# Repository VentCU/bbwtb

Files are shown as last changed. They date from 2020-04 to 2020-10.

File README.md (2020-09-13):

# VentCU
> A radically accessible, affordable, and producible ventilator. 

## VentCU has not been clinically tested. It is NOT approved for medical use.

## What is VentCU?
In response to the initial explosion in demand for ventilators caused by the global COVID-19 crisis, VentCU was developed as an intermediary manual ventilation device for clinical use.  Designed in collaboration with medical professionals and skilled engineers, VentCU is positioned as a **radically affordable** device able to be **assembled with no prior experience and no specialized tools**.  *Constructed entirely from consumer-off-the-shelf parts*, available in the hundreds to thousands in a matter of days, hospital technicians and maker enthusiasts alike will be able to construct VentCU with nothing more than an instruction manual, an Allen key, a pair of scissors, and a soldering iron.

The critical demand for ventilators that sparked VentCU’s conception has thankfully subsided since the beginning of the COVID-19 crisis.  However, VentCU continues as an area of research to be used in further development of affordable, easily manufacturable ventilators should another surge for ventilators emerge or for communities already lacking access to proper ventilation devices.  **As such, VentCU is completely open-source.**

## [VentCU Website](https://coda.io/@maker/ventcu) 
Check out our website (https://coda.io/@maker/ventcu) for detailed technical, BOM, and contact information.
Also, feel free to share our work on social media!

# Repository Structure
> `version 0.1-alpha`
How to install the repo in an open terminal window on your VentCU device's Raspberry Pi 3 B+:
```
cd $HOME
mkdir Workspace
cd Workspace
git clone https://github.com/VentCU/bbwtb.git
```

## Electronics
An electronics layout and next-generation PCB of the VentCU device is viewable in the `electronics` directory. 

## Mechanics
A stable release of the VentCU device main assembly can be found within the `mechanics` directory. A viewable, online CAD model with complete relationships can viewed at this [Onshape link](https://cad.onshape.com/documents/f7de46ca7dc3a8d28aa71883/w/2f9839ab30d7aa3f0e55734c/e/351b5eba45a0f5e74e63c1ba).

A user manual and specification sheet can be found in the stable release directory in the `mechanics` directory and viewed online at this [Google Docs link](https://docs.google.com/document/d/146-ZcDFsmwu9b4q7zNh3ngux9tSg6TSOEBYOS_3Alh4/edit?usp=sharing)

## Media
CAD renders and real-life pictures of the VentCU device can be viewed in the `media` directory.

## Software
The software repository contains code to run the VentCU device and instructions for installation. See `software\README.md` for a comprehensive system breakdown. 

## Repository Changelog
Newest on top.
09/12/2020: `version-0.1-alpha`: preliminary alpha release for first public publishing
09/03/2020: `version-0.0-alpha`: stable alpha for committee demo
### bbwtb

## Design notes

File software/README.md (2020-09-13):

# VentCU Software
> `version 0.1-alpha`

## Overview
VentCU runs currently on a Raspberry Pi 3 B+, Python 3, and PyQT application stack, relying on a touchscreen interface to view and control the device. We have mocked up our main control, homing, and UI state diagrams below:
### Main Control
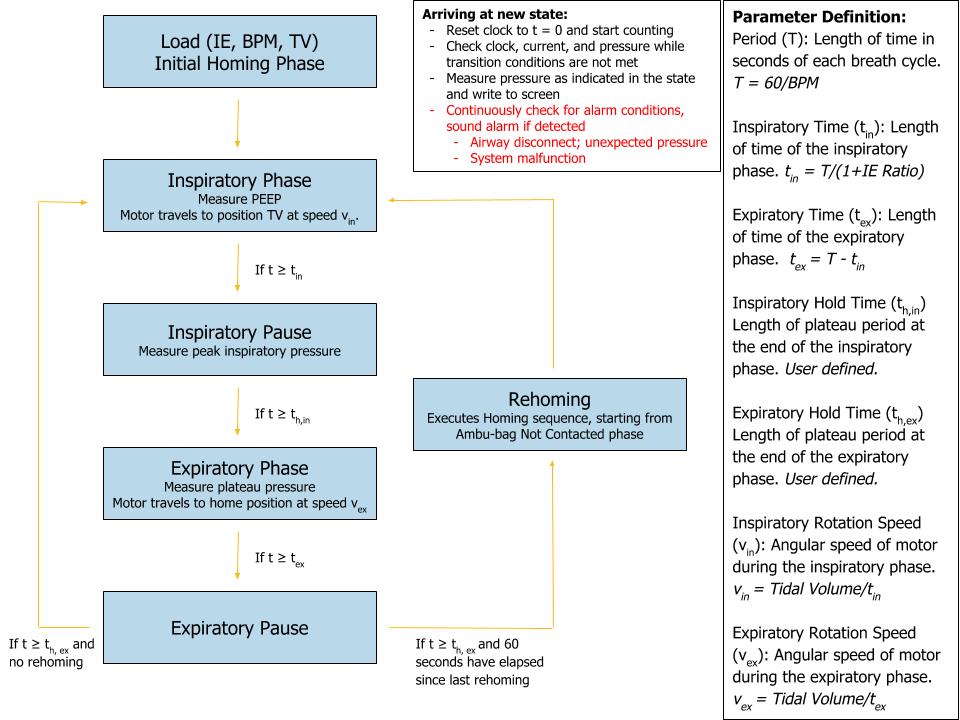
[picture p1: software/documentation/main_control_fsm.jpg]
main control

### Homing
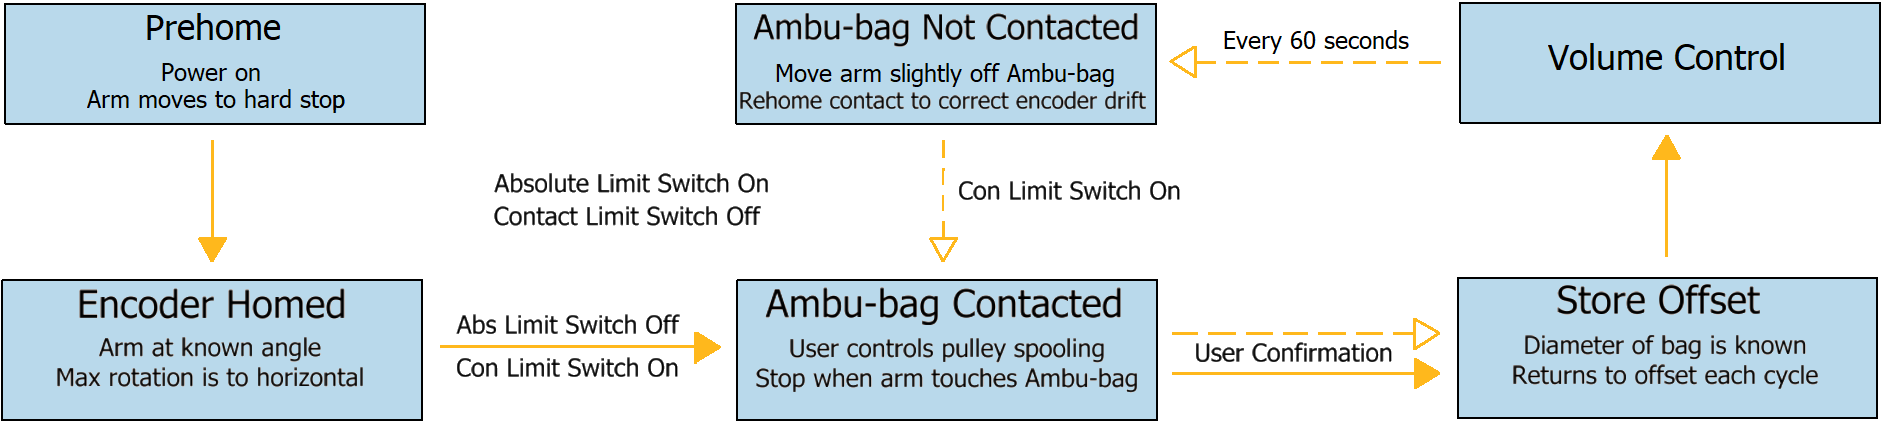
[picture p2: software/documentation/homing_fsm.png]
homing


## How to Setup Software
See pages 51-53 of the VentCU User Manual for exact instructions. See `control_system\setup-script.sh` for automation of Step 9 and 11.

## How to Run
See pages 54-57 of the VentCU User Manual for exact instructions. 

## Software Flow
See `control_system\README.md` for a file-by-file breakdown.

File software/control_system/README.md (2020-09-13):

# VentCU Control System
> `version 0.1-alpha`

## Code Flow
`ventilator.py` instantiates a `UIControllerInterface` and passes into it a `UI` and `VentilatorController`. <br>
`ventilator.py` creates a log file in the `\logs` directory. <br>
`ui_controller_interface.py` handles interactions between Qt UI event loop handling of user input and `VentilatorController` <br>
`ventilator_controller.py` instantiates low level sensors and actuators from respective `\sensors` and `\actuators` directories. <br>
`ventilator_controller.py` then handles core continuous ventilation state machine as seen in prior `README`. <br>

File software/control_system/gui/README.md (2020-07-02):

This document provides information about the GUI functionality that needs to be implemented as of 5/24/2020. Reach to to Delphine about any questions.
This is all written with the assumption that the GUI consists of seperate UI files, where each is unhidden/hidden as needed.

start.ui -> first screen that shows up when ventilator is turned on
-Clicking start_button should close current window and open start_homing.ui

start_homing.ui -> screen that allows user to start homing procedure
-Clicking start_button should close current window and open homing.ui. Must also send signal to Raspberry Pi to begin homing procedure.
-Clicking cancel_button should close current window and open start.ui

homing.ui -> waiting screen during homing process
-No buttons are present on this page. Raspberry Pi should send a signal after homing procedure is finished causing current window to close and open confirm_homing.ui

confirm_homing.ui -> user must verify measured Ambu bag size
-Raspberry Pi must send identified bag diameter. bag_size_label must be set to this number. Should be formated as bagsize + '' (Ex: 8'')
-Clicking rehome_button should close current window and open homing.ui. Must also send signal to Raspberry Pi to begin homing procedure
-Clicking confirm_button should close current window and open edit_parameters.ui window.

edit_parameters.ui -> screen for user to modify parameters
-TV_label is preset to some reasonable number (ex: 500 ml). Clicking tidal_increase_button or tidal_decrease_button should increase or decrease tidal_volume_label by 5ml respectively. (***NOTE: more research should be done in limits of reasonable tidal volume to inform starting and increment values)
-BPM_label is preset to some reasonable number (ex: 40). Clicking bpm_increase_button or bpm_decrease_button should increase or decrease bpm_label by 1 repectively. (***NOTE: more research should be done in limits of reasonable bpm to inform starting and increment values)
-IE_label is preset to some reasonable number (ex: 1:2). Clicking ie_increase_button or ie_decrease button should increase of decrease the ie_ratio_label. Research should be done to determine what incrementing I:E ratio means. Ex: 2:1, 1:2, 1:3, 1:4...
-Clicking set_button should close current window and open confirm_parameters.ui
-Clicking back_button should close current window and open main.ui. Back button should be HIDDEN if this is the first time turing on ventilator (ie should not be possible to jump to main screen without first confirming parameters)

confirm_parameters.ui -> user must review and confirm parameters before they are enacted
-confirm_bpm_label, confirm_ie_label and confirm_tidal_label must all be set their corresponding values from their counterparts in edit_paramters.
-Clicking confirm_button should close current window and open main_screen.ui
-Clicking cancel_button should close current window and open edit_parameters.ui

main_window.ui -> default window shown during ventilation that shows status of different parameters/pressure readings
Note: this screen is exactly the same as mock.ui but only contains pressure graph
-Graphs (pressure_graph and volume_graph) must receive and plot pressure readings from Pi-Clicking edit_parameters_button should close current window and open edit_parameters.u
-NEW: set_TV_label, set_BPM_label, set_IE_label, set_PIP_label, set_PEEP_label, set_PLAT_label should all display user settings for the parameters (or preset thresholds for pressures)
-NEW: measured_TV_label, measured_BPM_label, measured_IE_label, measured_PIP_label, measured_PEEP_label, measured_PLAT_label should display measured pressures and parameters
-NEW: message_log_label should display appropriate message (alarm message, nothing etc.)

alarm_condidtion.ui -> shown when alarm condition is triggered
-Raspberry Pi must send alarm signal. Current window closes and alarm_condition.ui is shown.
-error_message_label is set to text corresponding to alarm condition sent by the Pi
-dismiss_alarm_button closes current window and opens main_screen.ui. Signal is sent to Pi to silence alarm.
-silence_alarm_button closes current window and opens main_screen.ui. Signal is sent to Pi to silence alarm for 2 minutes.

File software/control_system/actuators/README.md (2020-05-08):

## Dependencies

`smbus2`

`pySerial`

## Please READ regarding I2C

The example C code below uses the I²C API provided by the Linux kernel to send and receive data from a Tic. It 
demonstrates how to set the target position of the Tic and how to read variables from it. This code only works on Linux.

If you are using a Raspberry Pi, please note that the Raspberry Pi’s hardware I²C module has a bug that causes this 
code to not work reliably. As a workaround, we recommend enabling the i2c-gpio overlay and using the I²C device that 
it provides. To do this, add the line dtoverlay=i2c-gpio to /boot/config.txt and reboot. The overlay documentation has 
information about the parameters you can put on that line, but those parameters are not required. Connect the Tic’s 
SDA line to GPIO23 and connect the Tic’s SCL line to GPIO24. The i2c-gpio overlay creates a new I²C device which is 
usually named /dev/i2c-3, and the code below uses that device. To give your user permission to access I²C busses without 
being root, you might have to add yourself to the i2c group by running sudo usermod -a -G i2c $(whoami) and restarting.

You might notice that the Tic only performs the desired movement for about a second before it stops moving and the red 
LED turns on, indicating an error. This is because of the Tic’s command timeout feature: by default, the Tic’s 
“Command timeout” error will happen if it does not receive certain commands periodically (see Section 5.4 for details), 
causing the motor to stop. You can send a “Reset command timeout” command every second to get around this, or you can 
disable the command timeout feature using the Tic Control Center: uncheck the “Enable command timeout” checkbox in 
the “Serial” box.

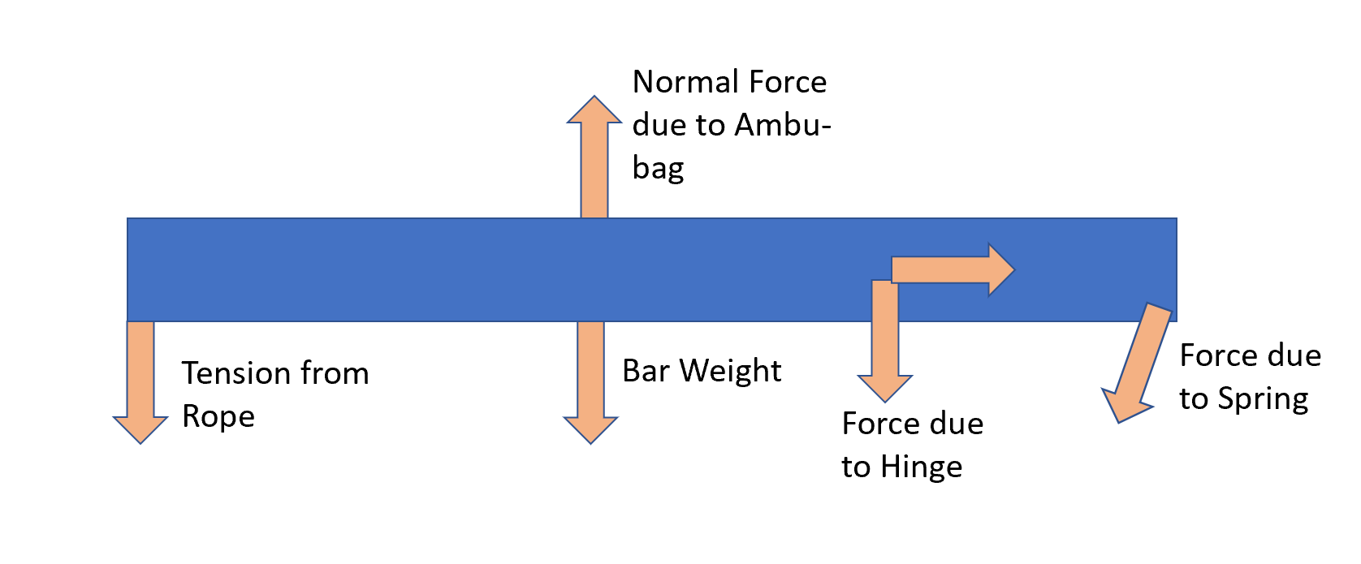
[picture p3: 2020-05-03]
mechanics/images/delphine_fbd.png

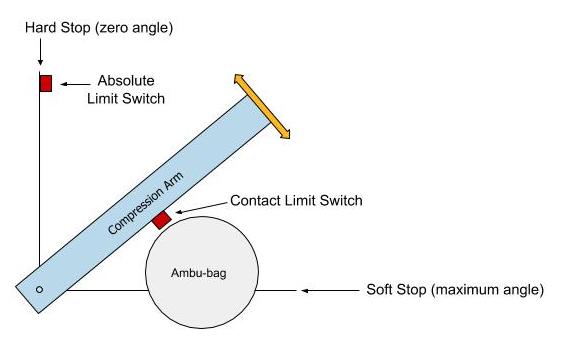
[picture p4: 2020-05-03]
mechanics/images/compression_arm_homing_diagram.jpg

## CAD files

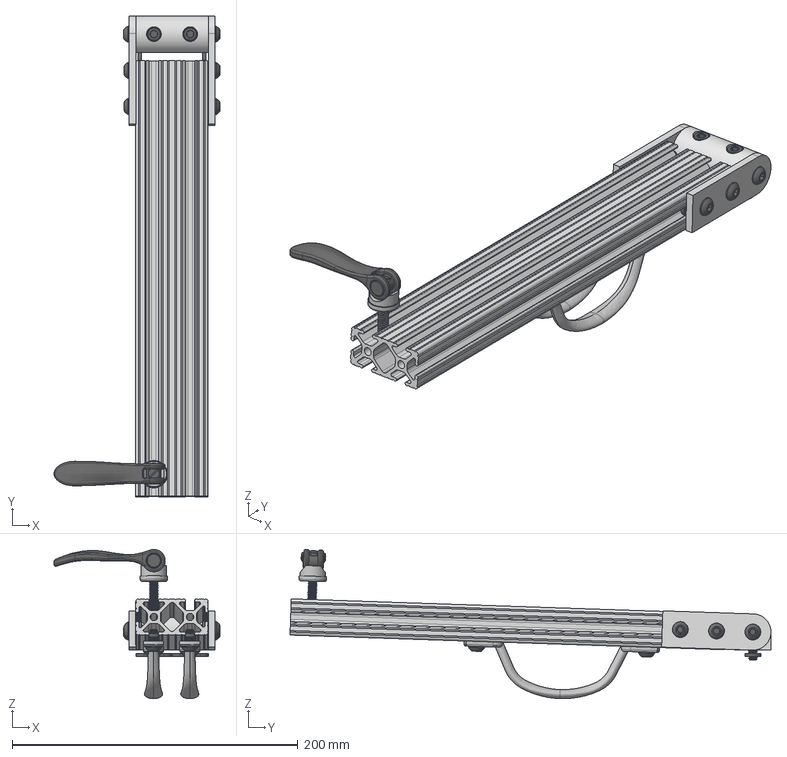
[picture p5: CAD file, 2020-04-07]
mechanics/rfp_submission/compressionarm/compression_arm.step
116.1 x 336.8 x 104.5 mm
T-Slot Nut x 8
Button Head 1/4"-20, 1/2" Screw x 8
Unthreaded-Hole Oval Pull Handle x 2
T-Slot Double Wide Extrusion, 1ft
Clamping Handle with Threaded Stud x 3
Inline/Perpendicular Pivot for 2" Double/Quad T-Slot x 9

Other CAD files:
software/documentation/homing_state_machine.ipt

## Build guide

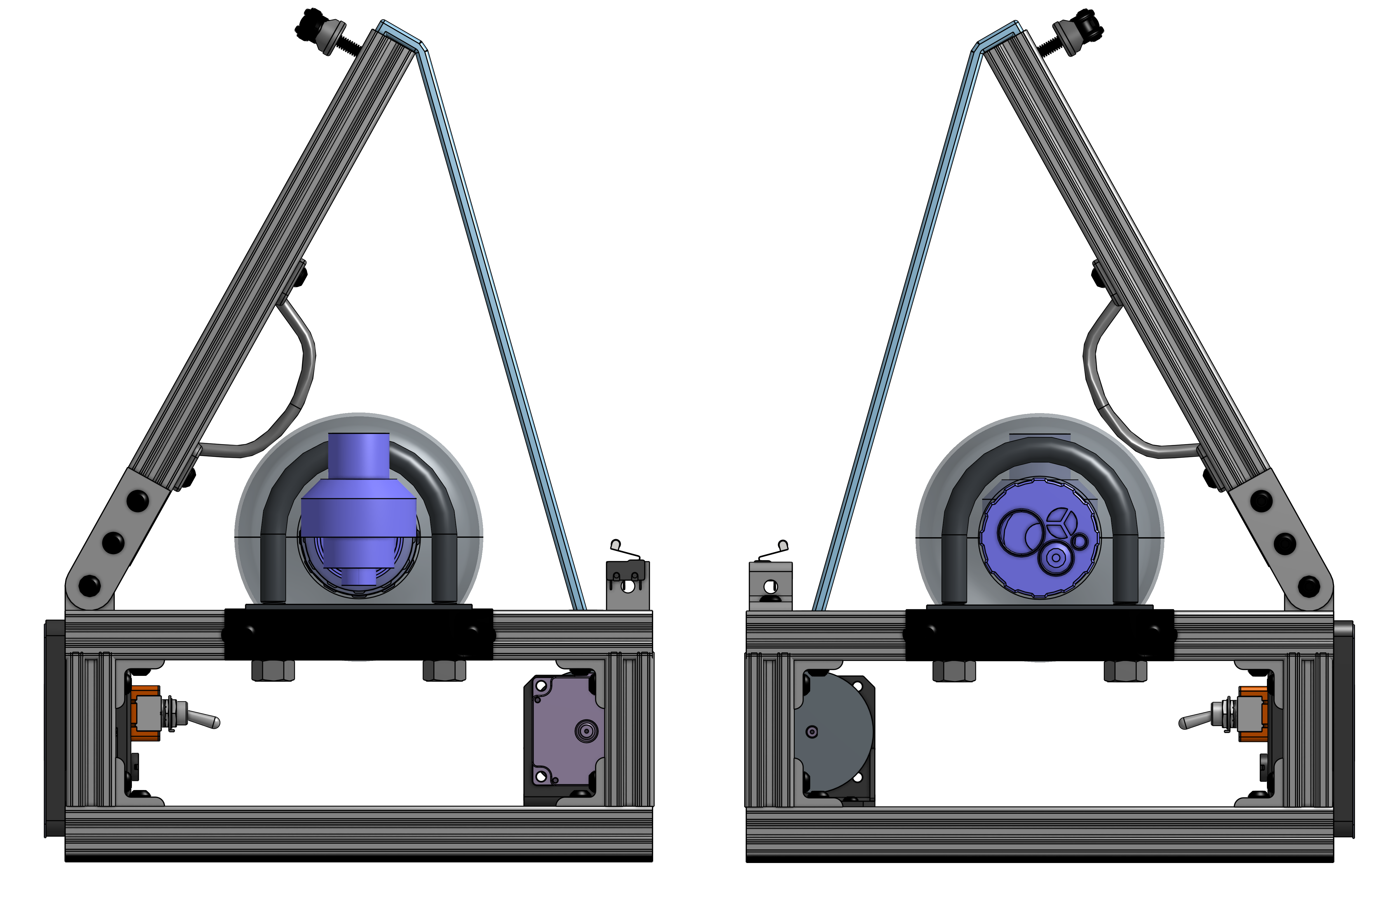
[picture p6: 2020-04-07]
media/v1/Main Assembly left and right side view.png

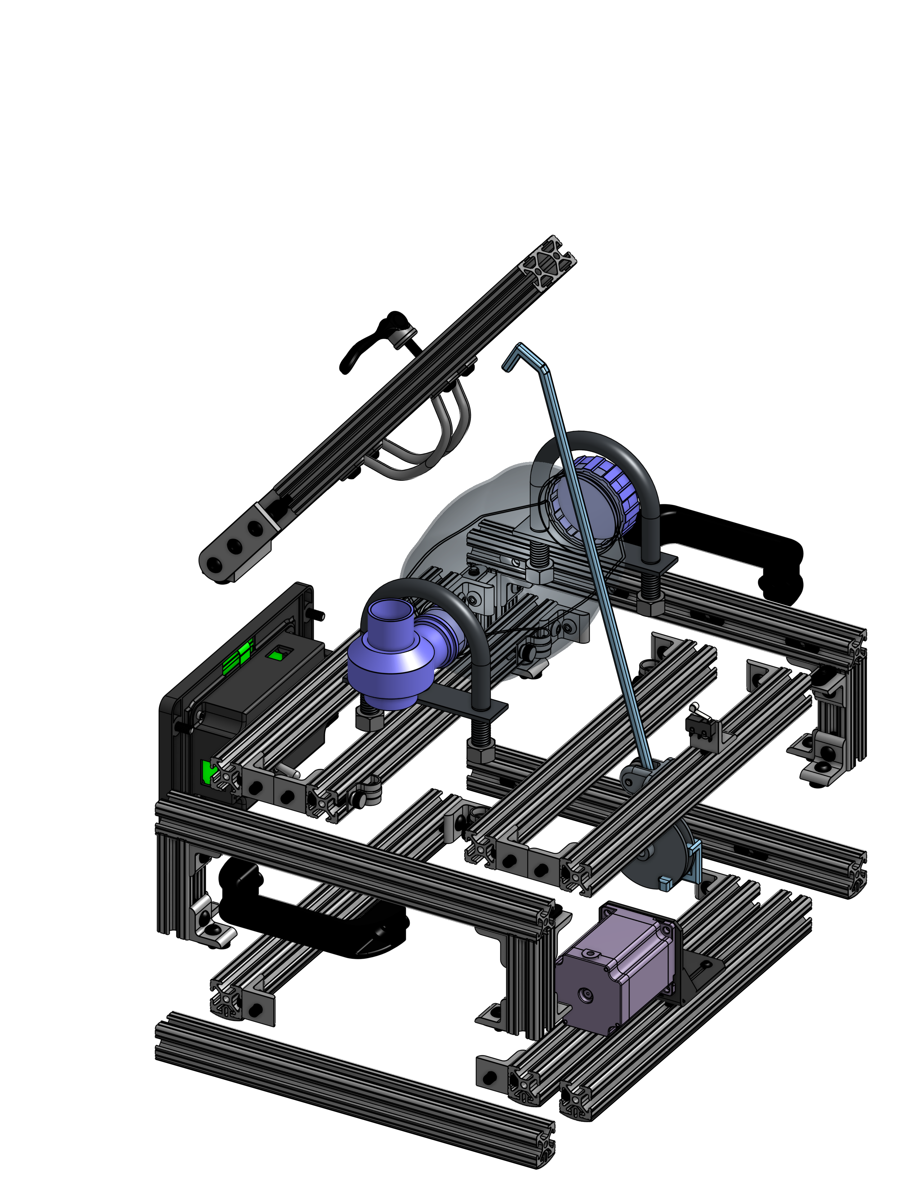
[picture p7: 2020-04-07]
media/v1/Main Assembly exploded view.png

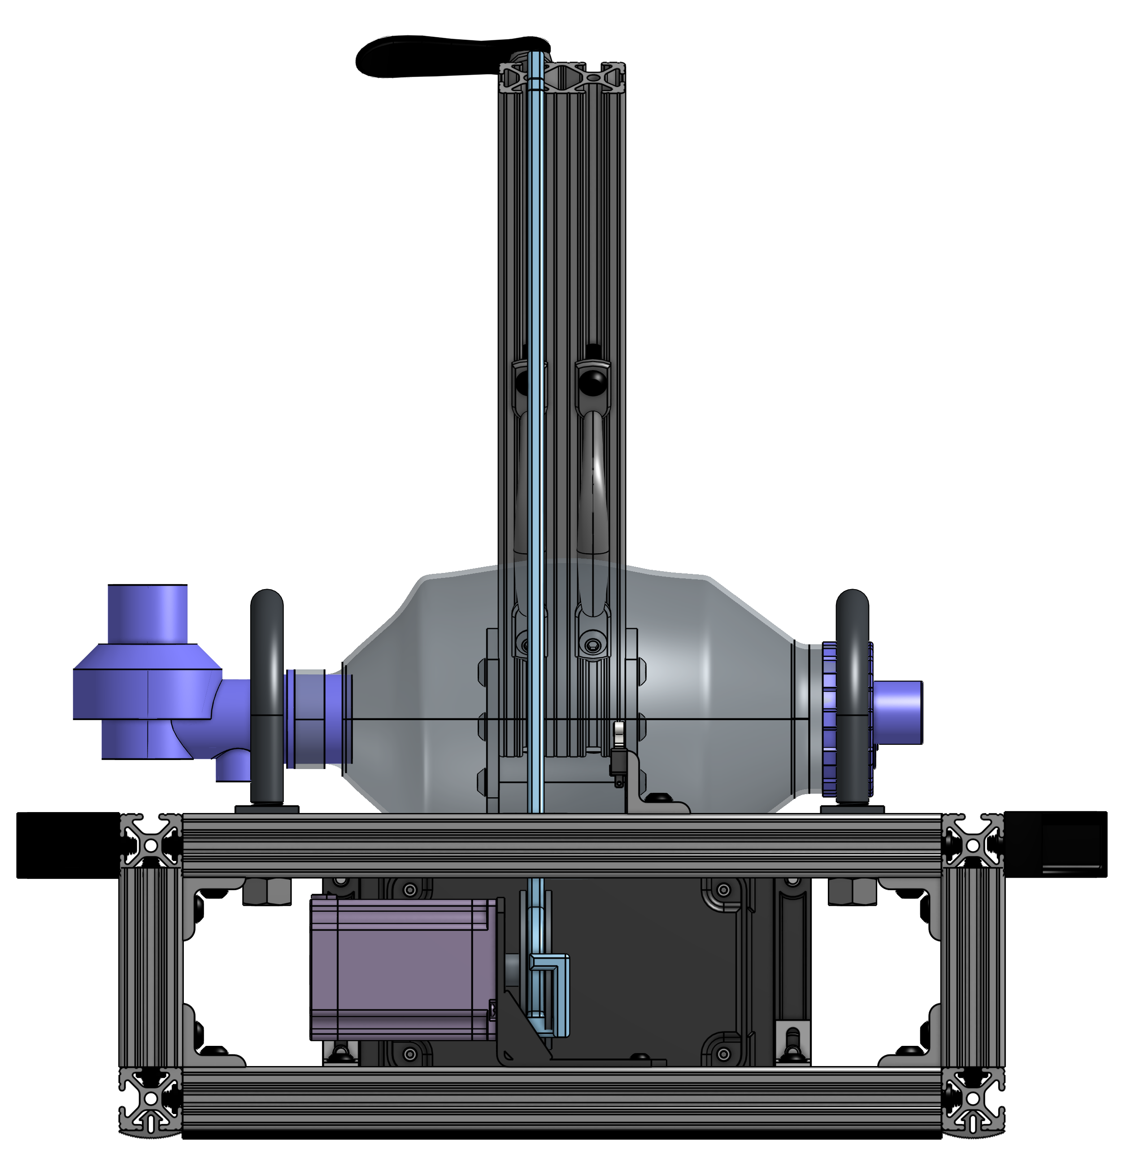
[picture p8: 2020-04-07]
media/v1/Main Assembly front view.png

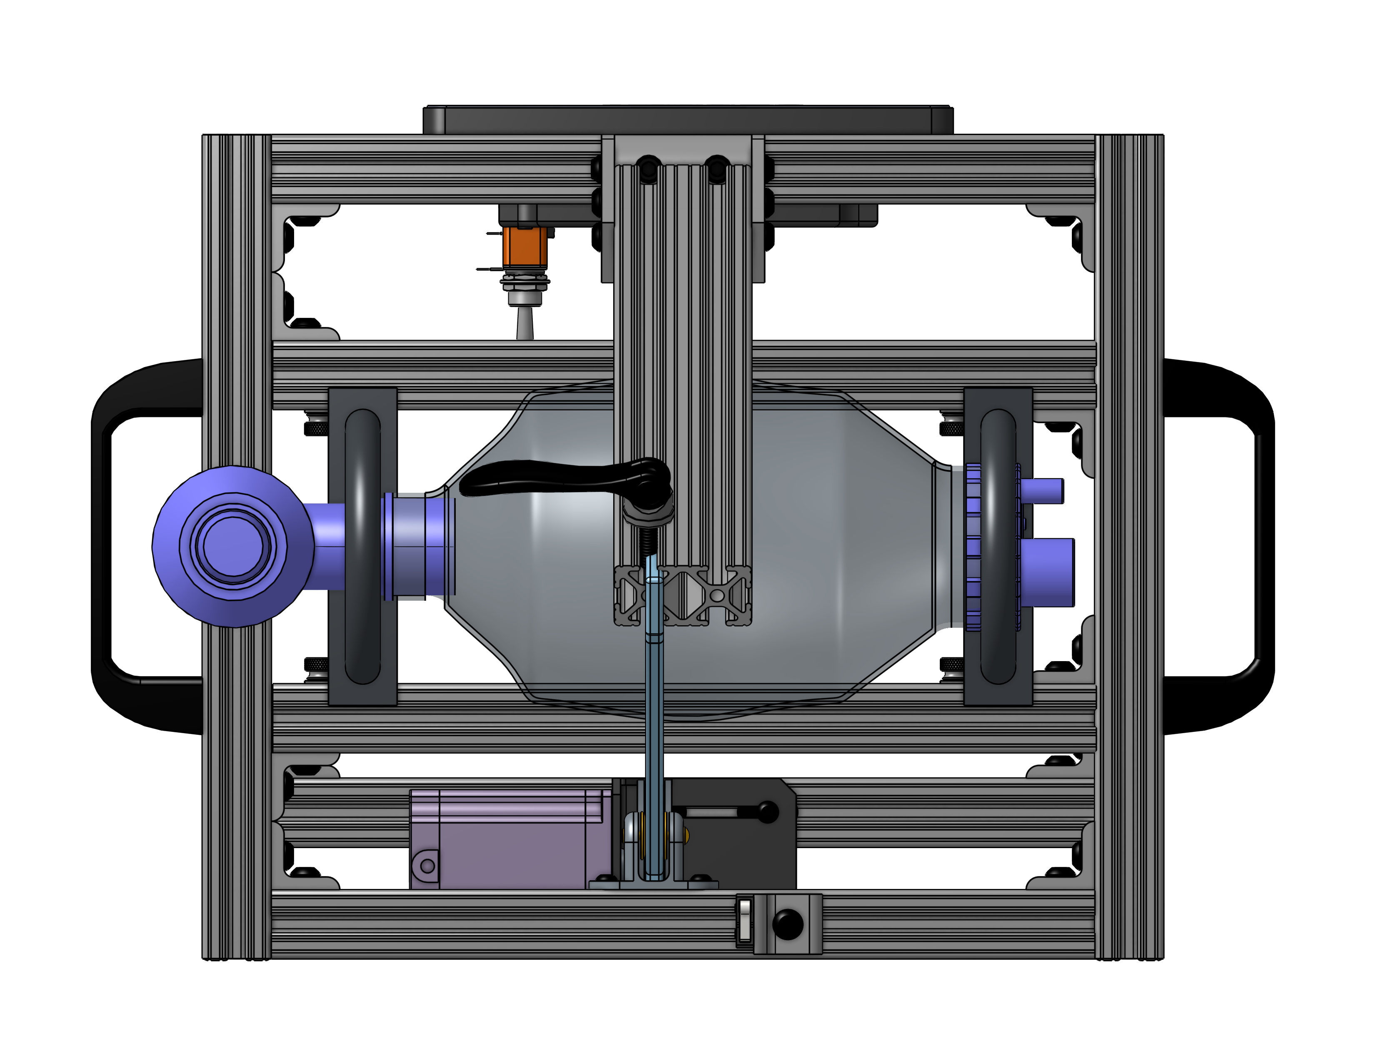
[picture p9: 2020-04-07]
media/v1/Main Assembly top view.png

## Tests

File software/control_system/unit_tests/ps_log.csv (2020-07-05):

Time (0.01s) | Raw | Conv
0 | 4468 | -0.5681696803234912
1 | 4531 | -0.5585564965285725
2 | 4571 | -0.552452887769894
3 | 4565 | -0.5533684290836958
4 | 4545 | -0.556420233463035
5 | 4475 | -0.5671015487907225
6 | 4523 | -0.5597772182803082
7 | 4555 | -0.5548943312733654
8 | 4567 | -0.5530632486457618
9 | 4547 | -0.5561150530251011
10 | 4484 | -0.5657282368200198
11 | 4521 | -0.5600823987182422
12 | 4562 | -0.5538261997405967
13 | 4561 | -0.5539787899595636
14 | 4524 | -0.5596246280613413
15 | 4475 | -0.5671015487907225
16 | 4530 | -0.5587090867475395
17 | 4587 | -0.5500114442664226
18 | 4572 | -0.552300297550927
19 | 4529 | -0.5588616769665065
20 | 4519 | -0.5603875791561761
21 | 4574 | -0.5519951171129931
22 | 4547 | -0.5561150530251011
23 | 4494 | -0.5642023346303502
24 | 4489 | -0.564965285725185
25 | 4536 | -0.5577935454337377
26 | 4588 | -0.5498588540474556
27 | 4561 | -0.5539787899595636
28 | 4501 | -0.5631342030975814
29 | 4491 | -0.5646601052872511
30 | 4533 | -0.5582513160906386
31 | 4586 | -0.5501640344853895
32 | 4558 | -0.5544365606164645
33 | 4486 | -0.5654230563820859
34 | 4520 | -0.5602349889372091
35 | 4546 | -0.5562676432440681
36 | 4596 | -0.5486381322957199
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

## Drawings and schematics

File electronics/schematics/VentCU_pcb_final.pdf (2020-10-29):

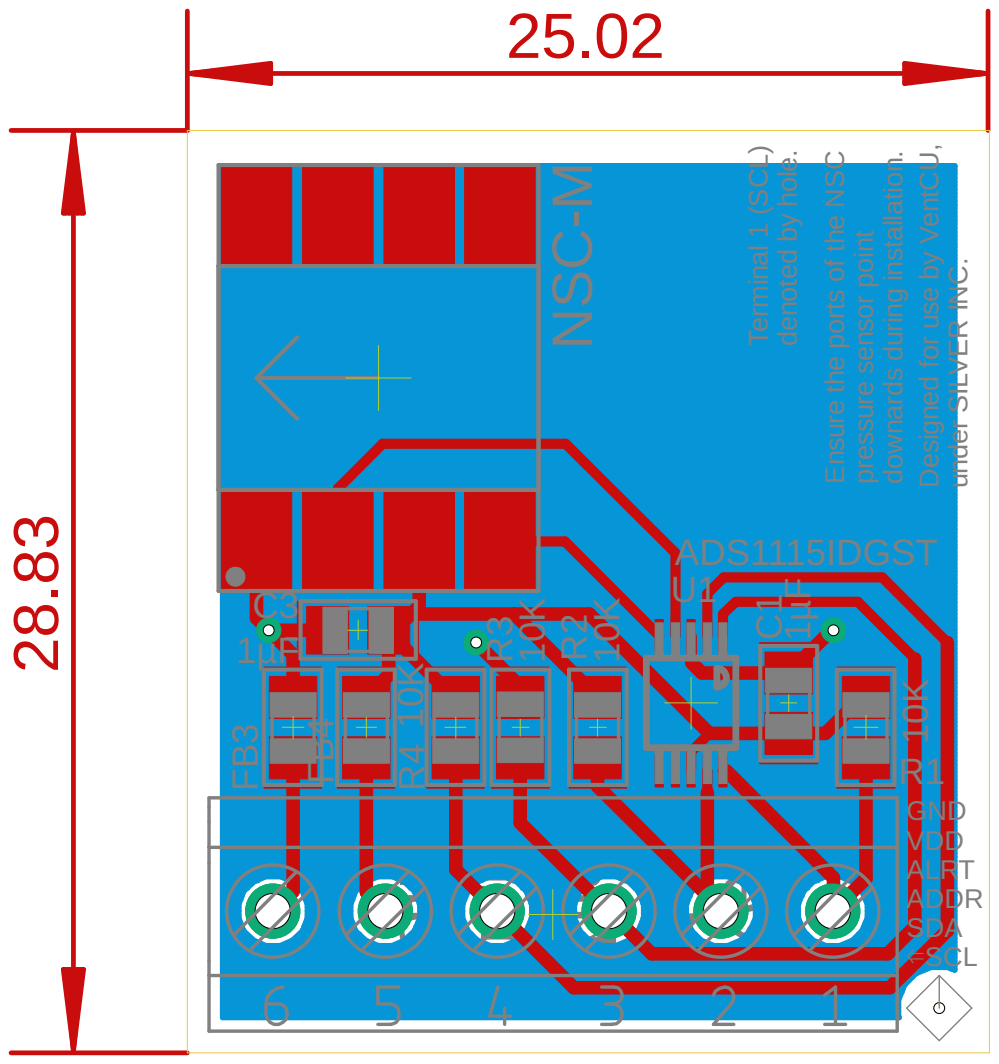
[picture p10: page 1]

Read the VentCU User Manual before using this PCB. Improper handling can cause failure during operation. 25.02 28.83 Designed for use by VentCU, under SILVER INC. GND VDD ALRT ADDR SDA ⇐SCL Terminal 1 (SCL) denoted by hole. Ensure the ports of the NSC pressure sensor point downards during installation. CC3 1 FB3 FB4 R1 R2 R3 R4 NSC-M U1 1µF 1µF 10K 10K 10K 10K ADS1115IDGST

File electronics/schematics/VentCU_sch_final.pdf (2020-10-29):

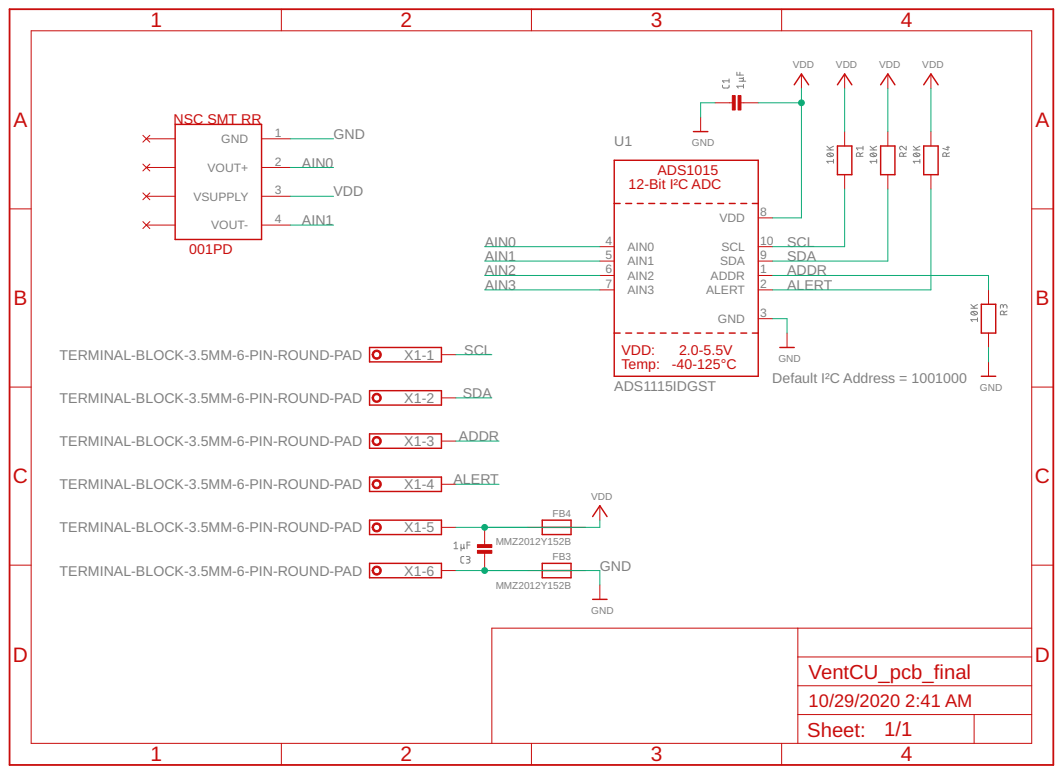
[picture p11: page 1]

TERMINAL-BLOCK-3.5MM-6-PIN-ROUND-PAD

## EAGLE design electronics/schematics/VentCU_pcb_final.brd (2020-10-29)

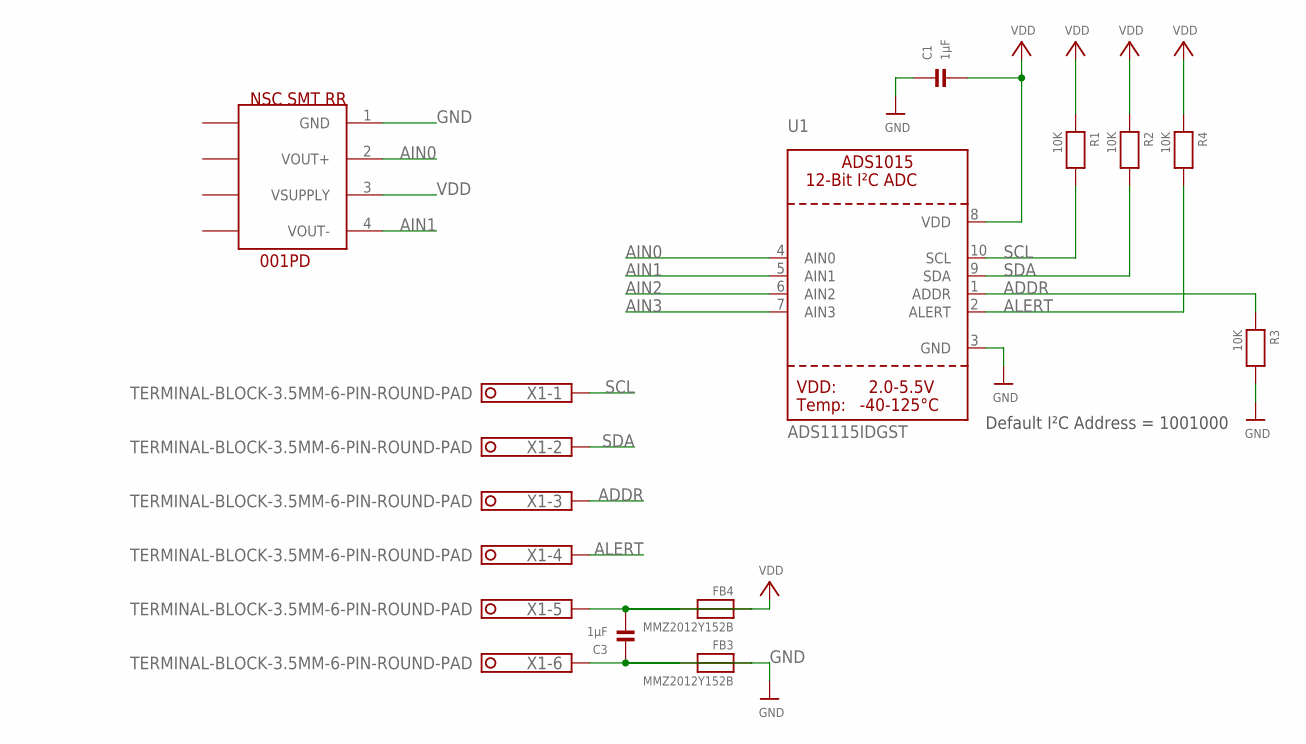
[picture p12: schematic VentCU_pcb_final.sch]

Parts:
C1, C3: 1µF; 0805
FB3, FB4: MMZ2012Y152B; 0805
R1, R2, R3, R4: 10K; 0805
U1: ADS1115IDGST; MSOP10
U$1: NSC-M
X1: TERMINAL-BLOCK-3.5MM-6-PIN-ROUND-PAD; TERMINAL-BLOCK-6-PIN-3.5MM-ROUND-PAD

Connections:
ADDR: R3.1, U1.1 (ADDR), X1.3
AIN0: U1.4 (AIN0), U$1.2 (VOUT+)
AIN1: U1.5 (AIN1), U$1.4 (VOUT-)
AIN2: U1.6 (AIN2)
AIN3: U1.7 (AIN3)
ALERT: R4.2, U1.2 (ALERT), X1.4
GND: C1.1, C3.1, FB3.1, R3.2, U1.3 (GND), U$1.1 (GND)
unnamed: FB4.2, X1.5
unnamed: FB3.2, X1.6
SCL: R1.2, U1.10 (SCL), X1.1
SDA: R2.2, U1.9 (SDA), X1.2
VDD: C1.2, C3.2, FB4.1, R1.1, R2.1, R4.1, U1.8 (VDD), U$1.3 (VSUPPLY)

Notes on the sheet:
Default I²C Address = 1001000

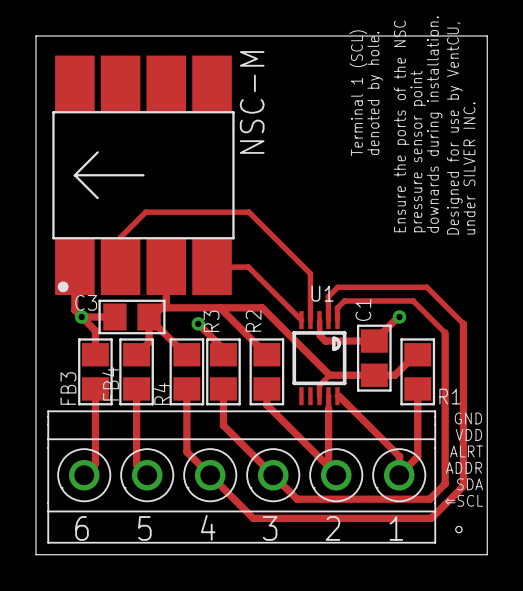
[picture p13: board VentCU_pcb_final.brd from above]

Board: 2 copper layers, 25.1 x 28.8 mm, 11 parts (0 on the bottom side), 10 nets.

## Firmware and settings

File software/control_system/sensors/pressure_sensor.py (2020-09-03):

#
# Pressure Sensor Class
# Implemented with an analog-digital converter communicating over I2C
#
import board
import busio
import adafruit_ads1x15.ads1115 as ADS
from adafruit_ads1x15.analog_in import AnalogIn
from time import sleep
import matplotlib.pyplot as plt
import numpy as np
import logging

plt_logger = logging.getLogger('matplotlib')
plt_logger.setLevel(logging.CRITICAL)


class PressureSensor:

    def __init__(self):

        print("NOT IMPLEMENTED")
        # default i2c port set to 48
        # default i2c communication on pins 3, 5 of pi
        self.i2c = busio.I2C(board.SCL, board.SDA)
        self.ads = ADS.ADS1115(self.i2c)
        self.raw_pressure = 0
        self.voltage = 0

    def update_data(self):
        chan = AnalogIn(self.ads, ADS.P0, ADS.P1)
        self.raw_pressure = chan.value
        self.voltage = chan.voltage

    # Returns raw differential reading from pressure sensor
    # Pressure transducer hard wired to ADC analog pins 0, 1
    def get_raw_pressure(self):
        return np.sqrt(np.square(self.raw_pressure))
    
    def get_voltage(self):
        return self.voltage

    # TODO: Implement
    def get_pressure(self):
        # remove raw2data later
        pressure = raw2data(self.raw_pressure)
        return pressure

# takes channel data from transducer and coverts to psi
def raw2data(value):
    output_max = 14745 #psi
    output_min = 1638 #psi
    pressure_max = 1
    pressure_min = -1
    output = (((value - output_min) * 
              (pressure_max - pressure_min))/
              (output_max - output_min)) + pressure_min
    return output

def i2c_test():
    i2c = busio.I2C(board.SCL, board.SDA)
    ads = ADS.ADS1115(i2c)

    values = []
    ctr = 0
    chan0 = AnalogIn(ads, ADS.P0, ADS.P1)
    chan1 = AnalogIn(ads, ADS.P2, ADS.P3)
#    chan2 = AnalogIn(ads, ADS.P2)
#    chan3 = AnalogIn(ads, ADS.P3)
    while(ctr < 5):
        sleep(0.1)
        pressure = raw2data(chan0.value)
        values.append(pressure)
        ctr += 1
        print("ch0: ", pressure, chan0.voltage)
#        print("ch1: ", chan1.value, chan1.voltage)
#        print("ch2: ", chan2.value, chan2.voltage)
#        print("ch3: ", chan3.value, chan3.voltage)
        
    time = np.arange(ctr)
    # plt.plot(time, np.asarray(values))
    # plt.show()

if __name__ == "__main__":
    # i2c_test()
    i2c_test = PressureSensor()
    values_raw = []
    values_conv = []
    values_voltage = []
    ctr = 0
    while (ctr < 2000):
        sleep(0.01)
        i2c_test.update_data()
        raw = i2c_test.get_raw_pressure()
        conv = i2c_test.get_pressure()
        voltage = i2c_test.get_voltage()
        values_raw.append(raw)
        values_conv.append(conv)
        values_voltage.append(voltage)
        # print( f"Raw: {raw} Conv: {conv}")
        ctr += 1
    time = np.arange(ctr)

    fd = open('../unit_tests/ps_log.csv', 'w')
    header = 'Time (0.01s), Raw, Conv, Voltage'
    fd.write(header)
    fd.write('\n')
    for t, raw, conv, voltage in zip(time, values_raw, values_conv, values_voltage):
        line = f"{t}, {raw}, {conv}, {voltage}"
        fd.write(line)
        fd.write('\n')

    fig, (ax1, ax2, ax3) = plt.subplots(3)
    fig.suptitle('Raw, Conv Pressure Readings vs Time (0.01s)')
    ax1.plot(time, np.asarray(values_raw))
    ax2.plot(time, np.asarray(values_conv))
    ax3.plot(time, np.asarray(values_voltage))
    plt.show()

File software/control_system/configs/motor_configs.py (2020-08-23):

'''
# max accel: 1000000 pulses/s^2
# max speed: 50000 pulses/s
# 1/64 step
# pos target: +/- 12800
# 0.87s ttt (time to target) on pid_tuning.py
# mv_enc_pos_test: ttt: 1s true: 0.4s
# performance increase: 2.5x

PID_P_GAIN = 2300000
PID_I_GAIN = 0
PID_D_GAIN = 0

PID_TIME_SCALE_FACTOR = 0.01555
'''
# max accel: 1000000 pulses/s^2
# max speed: 30000 pulses/s
# 1/64 step

PID_P_GAIN = 1070000
PID_I_GAIN = 0
PID_D_GAIN = 0 # 100000

# PID_TIME_SCALE_FACTOR = 0.01555 # for 100 ticks (half rotation)
PID_TIME_SCALE_FACTOR = 0.00725 # for 250 ticks 
# PID_TIME_SCALE_FACTOR = 0.00615 # for 300 ticks
# PID_TIME_SCALE_FACTOR = 0.00415 # for 500 ticks
# PID_TIME_SCALE_FACTOR = 0.0035 # for 650 ticks

# PID_P_GAIN = 5200000
# PID_I_GAIN = 0
# PID_D_GAIN = 0 # 100000

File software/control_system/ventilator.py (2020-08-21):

#
# main ventilator class
# VentCU - An open source ventilator
#
# (c) VentCU, 2020. All Rights Reserved.
#

import signal
import sys
import pigpio

from logger import LoggerInit
from actuators.motor import Motor
from sensors.rotary_encoder import RotaryEncoder
from sensors.limit_switch import LimitSwitch
from sensors.power_switch import PowerSwitch
from sensors.pressure_sensor import PressureSensor
from configs.gpio_map import *
# from sensors.flow_sensor import FlowSensor

from ventilator_controller import VentilatorController
from gui.ui import UI
from ui_controller_interface import UIControllerInterface


class Ventilator:

    def __init__(self):

        # start logger
        logger = LoggerInit("ventilator")

        # instantiate sensors
        self.encoder = RotaryEncoder(pigpio.pi(), ENCODER_B_PLUS_PIN, ENCODER_A_PLUS_PIN)
        self.contact_switch = LimitSwitch(CONTACT_SWITCH_PIN)
        self.absolute_switch = LimitSwitch(ABSOLUTE_SWITCH_PIN)
        self.power_switch = PowerSwitch(POWER_SWITCH_PIN)
        # self.pressure_sensor = PressureSensor()
        # self.flow_sensor = FlowSensor(FLOW_SENSOR_PIN)

        # instantiate actuators
        self.motor = Motor(self.encoder)

        # instantiate controller
        self.controller = VentilatorController(self.motor,
                                               None,
                                               self.absolute_switch,
                                               self.contact_switch,
                                               self.power_switch)

        # instantiate ui
        self.ui = UI()

        self.ui_controller_interface = UIControllerInterface(self.ui, self.controller)
      
    def at_exit(self, sig, frame):
        print("Exiting program...")
        self.controller.stop_ventilation()
        # self.spirometer.stop() # stop data collection
        # self.spirometer.close()# disconnect from go direct device
        sys.exit(0)


def test():
    test_ventilator = Ventilator()
    signal.signal(signal.SIGINT, test_ventilator.at_exit)
    sys.exit(test_ventilator.ui.app.exec_())


if __name__ == "__main__":
    test()

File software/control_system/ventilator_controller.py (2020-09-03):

#
# ventilator controller class for
# VentCU - An open source ventilator
#
# (c) VentCU, 2020. All Rights Reserved.
# Contact: wx2214@columbia.edu
#          neil.nie@columbia.edu
#

from time import sleep
from datetime import datetime as time
import datetime
import logging
from configs.ventilation_configs import *
from alarms.alarms import *
from threading import Lock
from PyQt5.QtCore import pyqtSignal
from PyQt5 import QtCore
import sys
sys.path.append('/home/pi/Workspace/bbwtb/software/control_system/actuators')
from buzzer import Buzzer
sys.path.append('/home/pi/Workspace/bbwtb/software/control_system/sensors')
from pressure_sensor import PressureSensor


def add_secs(tm, secs):
    full_date = datetime.datetime(tm.year, tm.month, tm.day, tm.hour, tm.minute, tm.second, tm.microsecond)
    full_date = full_date + datetime.timedelta(seconds=secs)
    return full_date

def subtract_secs(tm, secs):
    full_date = datetime.datetime(tm.year, tm.month, tm.day, tm.hour, tm.minute, tm.second, tm.microsecond)
    full_date = full_date - datetime.timedelta(seconds=secs)
    return full_date

class State:
    def __init__(self, name):
        self.name = name

class StateChangeSender(QtCore.QObject):
    state_change_signal = pyqtSignal()

class ShutdownSender(QtCore.QObject):
    shutdown_signal = pyqtSignal()

class AlarmSender(QtCore.QObject):
    alarm_signal = pyqtSignal(Alarm)
    
class UpdateMeasuredParametersSender(QtCore.QObject):
    update_measured_parameters_signal = pyqtSignal() 
    
class VentilatorController:

    measured_parameters_sender = UpdateMeasuredParametersSender() 

    state_change_sender = StateChangeSender()
    shutdown_sender = ShutdownSender()
    alarm_sender = AlarmSender() 

    def __init__(self, motor, pressure_sensor,
                         upper_switch, lower_switch, power_switch ):
        self.buzzer_1 = Buzzer(25)
        self.buzzer_2 = Buzzer(8)

        # self.pressure_sensor = PressureSensor()

        #logger
        self.logger = logging.getLogger('ventilator_controller')

        # alarms
        self.current_alarms = []

        # states
        self.START_STATE = State("START_STATE")
        self.HOMING_STATE = State("HOMING_STATE")
        self.HOMING_VERIF_STATE = State("HOMING_VERIF_STATE")
        self.INSP_STATE = State("INSP_STATE")
        self.INSP_PAUSE_STATE = State("INSP_PAUSE")
        self.EXP_STATE = State("EXP_STATE")
        self.EXP_PAUSE_STATE = State("EXP_PAUSE_STATE")
        self.PAUSE_STATE = State("PAUSE_STATE")
        self.OFF_STATE = State("OFF_STATE")
        self.DEBUG_STATE = State("DEBUG_STATE")

        self.current_state = self.OFF_STATE
        self._entering_state = False
        self._state_lock = Lock()
        self._t_state_timer = 0                 # absolute time (s) at start of current state

        # cycle parameters
        self.cycle_count = 0
        self._t_cycle_start = time.now()        # absolute time (s) at start of cycle
        self._t_insp_end = time.now()           # calculated time (s) at end of insp
        self._t_insp_pause_end = time.now()     # calculated time (s) at end of insp pause
        self._t_exp_end = time.now()            # calculated time (s) at end of exp
        self._t_exp_pause_end = time.now()      # calculated time (s) at end of exp pause
        self._t_period = time.now()             # calculated time (s) at end of cycle
        self._t_period_actual = time.now()      # absolute time (s) at end of cycle
        self._t_loop_start = time.now()         # absolute time (s) at start of control loop

        # ventilation parameters
        self.volume = 400
        self.bpm = 20
        self.ie = 1

        # physical parameters
        self.bag_size = 7                       # diameter of the ambu bag (in)

        # localize actuators and sensors
        self.motor = motor
        self.pressure_sensor = pressure_sensor
        self.upper_switch = upper_switch
        self.lower_switch = lower_switch
        self.power_switch = power_switch

        self.lower_switch.callback = self.contact_switch_callback
        self.upper_switch.callback = self.limit_switch_callback
        self.power_switch.callback = self.power_switch_callback

        # motion get_variables
        self.bag_clear_pos = 0

        # motor helper variables
        self._pose_at_contact = 0               # position of the encoder when arm contacts ambu bag
        self._homing_dir = 1
        self.motor_lower_target = 0             # the target pose of motor when the arm is coming down.
        self.motor_upper_target = 0             # the target pose of motor when the arm is going up.
        self.motor_current_target = 0
        self.motor_prev_target = 0

        self.measure_volume = 0
        self.measure_bpm    = 0
        self.measure_ie     = {"insp_time":time.now(),"exp_time":time.now(),"last_exp_pause_end":time.now(),"ie_ratio":""}
        
        # TODO: clean up class variables
        # =========================================
        self.contact_encoder_val = 0    # at the point of contact of the ambu bag, what's the encoder value.
        self.contact_tic_val = 0
        self.abs_limit_encoder_val = 0  # at the point of abs limit, what's the encoder value.
        # =========================================


    #############################
    ## Base Method Definitions ##
    #############################

    # set the state of the finite state machine
    def set_state(self, state):
        """
        Calling set_state in a unsafe way is not defined.
        """

        self.logger.info("State change: " + self.current_state.name)

        with self._state_lock:
            self._entering_state = True
            self.current_state = state
            self._t_state_timer = time.now()

        self.logger.info(" --> " + self.current_state.name)

        self.state_change_sender.state_change_signal.emit()


    # calculate time parameters of ventilation
    def calculate_wave_form(self, tidal_volume, ie_ratio, bpm):

        self._t_period = 60.0 / bpm  # seconds per breath
        _t_period_end = add_secs(self._t_cycle_start, self._t_period)

        self._t_insp_pause_end = add_secs(self._t_cycle_start, self._t_period / (1 + ie_ratio))  # TODO: understand this
        self._t_insp_end = add_secs(self._t_cycle_start, (self._t_period / (1 + ie_ratio) - INSP_HOLD_DUR)) # self._t_cycle_start + self._t_insp_pause_end -   # TODO: understand this
        self._t_exp_end = min(add_secs(self._t_insp_pause_end, MAX_EXP_DUR),  # TODO: understand this
                              subtract_secs(_t_period_end, MIN_EXP_PAUSE))

        self._t_exp_pause_end = _t_period_end # add_secs(self._t_exp_end, MIN_EXP_PAUSE)
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

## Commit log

2020-04-07 CAD files and image documentation uploaded
    [compression_arm.step]
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2020-05-03 updated CAD models to match submission design
    [compression_arm.step]
2020-05-08 tic motor controller python classes added
2020-05-08 tic motor controller python example scripts added
2020-05-11 added sensor scripts (empty)
2020-05-11 added rotary encoder script
    ( please test @badinkajink ) thanks
2020-05-15 control script boilder plate added
2020-05-15 limited switch class added
2020-05-15 pressure sensor class added
    needs to be tested
2020-05-15 added set max speed and set starting speed
    tic motor controller. Please test @badinkajink
2020-05-16 turned rotary encoder script into class
    badly needs to be tested
2020-05-16 added new encoder code
2020-05-18 motor controller script updated
2020-05-18 Add limit switch test code
2020-05-18 added simple PID controller & test
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2020-05-18 added new pressure sensor script
2020-05-18 PID controller working, can bring motor to a state.
2020-05-18 pid control test finished and working
2020-05-18 updated motor controller script
2020-05-19 Begin stack structure plan: ventilator class, motor class, gpio map, move gui
2020-05-19 added new encoder code, better performance, not good enough
2020-05-19 updated the naming for tic_usb and encoder
    the new scripts should be fully integrated.
    the old scripts should have `old` appended to their names.
    fixed conflict in pid_control_test
    [pid_control_test.py, rotary_encoder.py, tic_test.py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]
2020-05-19 updated controller script, added homing procedure and test
2020-05-19 Re-work stack: encoder, motor, controller, ventilator
    - Integrated callback into RotaryEncoder
    - Switched RotaryEncoder logic to NC and added contacted function
    - Flushed out Motor class
    - Switched VentilatorController class to use a Motor
    - Added VentilatorController to Ventilator class
2020-05-19 integrated pid with motor class
2020-05-19 added a unit test for the motor class. cleaned up some old tests
2020-05-19 added contact limit switch gpio port
2020-05-21 pid tuning script tested, and motor test script updated
2020-05-21 Fix homing bugs; it works!
    [ventilator_controller.py]
2020-05-21 renamed tic device object, added set pose method
2020-05-21 motor movement code added
2020-05-21 basic arm movement script added
2020-05-26 organized file structure and README
    [homing_state_machine.0004.ipt]
2020-05-26 removed accidental legacy files, oops
    [alarm_conditions.xlsx]
2020-05-26 updated software documentation
    [alarm_conditions.xlsx, homing_state_machine.ipt]
2020-05-28 add minor improvements to the home() method
    add error checking for state machine safety. other small changes for code improvement.
    [ventilator_controller.py]
2020-05-30 add some error handling and some documentation
    [ventilator_controller.py]
2020-05-30 mapped buzzer gpio to gpio pin 25
    [gpio_map.py]
2020-05-31 fixed gui stack start button bug
    - fix app.exec_ issue.
    - fixed gui files paths
    [ui_controller_interface.py, ventilator.py, ventilator_controller.py]
2020-06-01 added pressure sensor unit test
2020-06-02 added gpio for power switch, test code for buzzer, integrated pressure sensor test script into class structure
    [buzzer.py, gpio_map.py, limit_switch.py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]
2020-06-06 patch calculate_wave_form method
    now the method won't crash anything : )
    [ventilator_controller.py]
2020-06-06 fix homing procedure bug
    [buzzer.py, limit_switch.py, motor.py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]
2020-06-08 Add basic threading to interface
2020-06-11 debugging ui_controller, just syntax errors so far
    [ui_controller_interface.py]
2020-06-11 Fixed edit parameters screen button
2020-06-13 Fix edit_parameters UI titles
    [ui_controller_interface.py]
2020-06-13 Fix main_window UI titles
    [ui_controller_interface.py]
2020-06-25 implemented Qt native threading
2020-06-27 Added buzzer pin
2020-06-28 fixed calling a method instead of feeding as an object in try_controller_method
    [ui_controller_interface.py]
2020-06-28 fixed try_controller_method for all other update methods
    [ui_controller_interface.py]
2020-06-28 Test two buzzers with beeping
    [buzzer.py]
2020-06-28 Stop motor if both switched hit while homing
2020-07-02 Fix type error for print message
    [ventilator_controller.py]
2020-07-02 added pressure sensor graphing, logging and some ventilator_controller debugging
2020-07-02 Fix default argument error
    [ui_controller_interface.py]
2020-07-02 added pressure sensor logging
2020-07-02 added pressure sensor log
    [ps_log.csv]
2020-07-02 Add dymanic element modification for parameters flow
2020-07-02 Spawn thread for rehoming
2020-07-02 Reset homing direction on homing completion
    [ventilator_controller.py]
2020-07-05 create power switch class
2020-07-05 add power switch to ventilator class
2020-07-05 add power switch to ventilator controller
2020-07-05 fix missing self in method
    [ui_controller_interface.py]
2020-07-06 Trigger state change from off switch
2020-07-07 Modify FSM homing logic
2020-07-07 Pause FSM with power_switch_callback
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2020-07-10 added slider widget to main gui, missing functionality
    [ui_controller_interface.py]
2020-07-18 added voltage plotting to pressure_sensor plotting script
2020-07-20 incorporated microseconds in subtract_seconds in calculate_waveform, potentially fixed issues
    [ventilator_controller.py]
2020-07-23 UI interface instance variable to control thread spawning upon interface parameter changes ( BPM, etc.)
2020-07-24 set motor current and prev target based on fsm states in update_tidal_volume
    If in EXP_STATE or INSP_PAUSE_STATE, set current target to motor_upper_target
    and prev_target to motor_lower_target.
    Else, set current target to motor_lower_target and prev_target to motor_upper_target
2020-08-06 Fix logger instantiation in ventilator
    [ventilator.py]
2020-08-06 Replace print statements with logs
    [ventilator.py, ventilator_controller.py]
2020-08-06 Fix log message formatting
    [ventilator_controller.py]
2020-08-21 Implementing framework for alarm handling gui.
2020-08-21 Homing Alarm Handling completed. Gui widget shown on except_alarm_hook signal.
2020-08-23 Update alarm widget text framework.
2020-08-23 Verify IE control works and implement correct PID_TIME_SCALE_FACTOR values for different distances
    [motor_configs.py, mv_to_enc_pos_test.py, pid_tuning.py]
2020-08-23 Implemented polynomially fitted PID scale factor through get_scale_factor(..).
2020-08-25 modify tic usb test to check that motor can meet max specification speed
2020-09-01 Adding rehome button to alarm_condition.ui.
2020-09-01 Updating 'dismiss_alarm_handler' slot connection to be the instance method object.
2020-09-01 Allowing controller object to access current_state attribute.
2020-09-01 connect gui close to motor destructor
2020-09-01 Connect gui close to controller stop ventilation rather than motor destructor
2020-09-03 Add true pressure sensor plotting to ui
2020-09-03 Extend y_axis of pressure sensor ui plot
2020-09-03 Reverse I:E to match set I:E
    [ventilator_controller.py]
2020-09-03 Enable buzzer sounding on alarms
    [ventilator_controller.py]
2020-09-03 Fix syntax assignment error on buzzers
    [ventilator_controller.py]
2020-09-03 add under pressure alarm implementation
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2020-09-03 take out pressure sensor and alarms for now
2020-09-12 Restructure test files to belong to individual actuators and sensors directories
2020-09-12 Remove deprecated software files
    [homing_state_machine.0004.ipt]
2020-09-13 update main assembly and move old one to new v2 directory
2020-09-13 update README and restructure mechanics repo into release versions
    [compression_arm.step]
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2020-10-23 board/schematic upload
    [VentCU_pcb_final.brd, VentCU_pcb_final.sch]
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2020-10-29 Updated design for better signal integrity, size
    [VentCU_pcb_final.brd, VentCU_pcb_final.sch]
